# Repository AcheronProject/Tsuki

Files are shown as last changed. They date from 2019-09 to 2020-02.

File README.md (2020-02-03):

# Acheron 60-SM-S-STM32-MX-TH-WI (Codename "Tsuki")

Acheron Logo

See [this page](https://gondolindrim.github.io/AcheronDocs/tsuki/intro.html) for the Tsuki documentation.

## Introduction

Tsuki is a universal 60% PCB, supporting per-key lighting using single-color LEDs, RGB underglow using WS2812C RGB LEDs and a multitude of layouts:

- Default ANSI bottom row;
- Classic HHKB (6.0u spacebar) bottom row;
- Tsangan bottom row (7.0u spacebar, also known as "simmetrical HHKB")
- Split backspace;
- Split left and right shifts;
- ISO and UK-ISO;
- ABNT and ABNT2 layouts.

Tsuki was heavily based on the [GH60](https://github.com/komar007/gh60), a legendary PCB designed by Komar with extensive feedback from the community.

## Contributors

- Raphael "ArcticFox" Hochheim for helping choosing the compatible layouts and the naming of the PCBs
- Felipe 'MrKeebs" Coury who paid for the V1 prototypes and helped immensely by funding my learning

## Renders

Click at the images to zoom in.

Renders generated by the [tracespace.io](https://tracespace.io/view/) site.

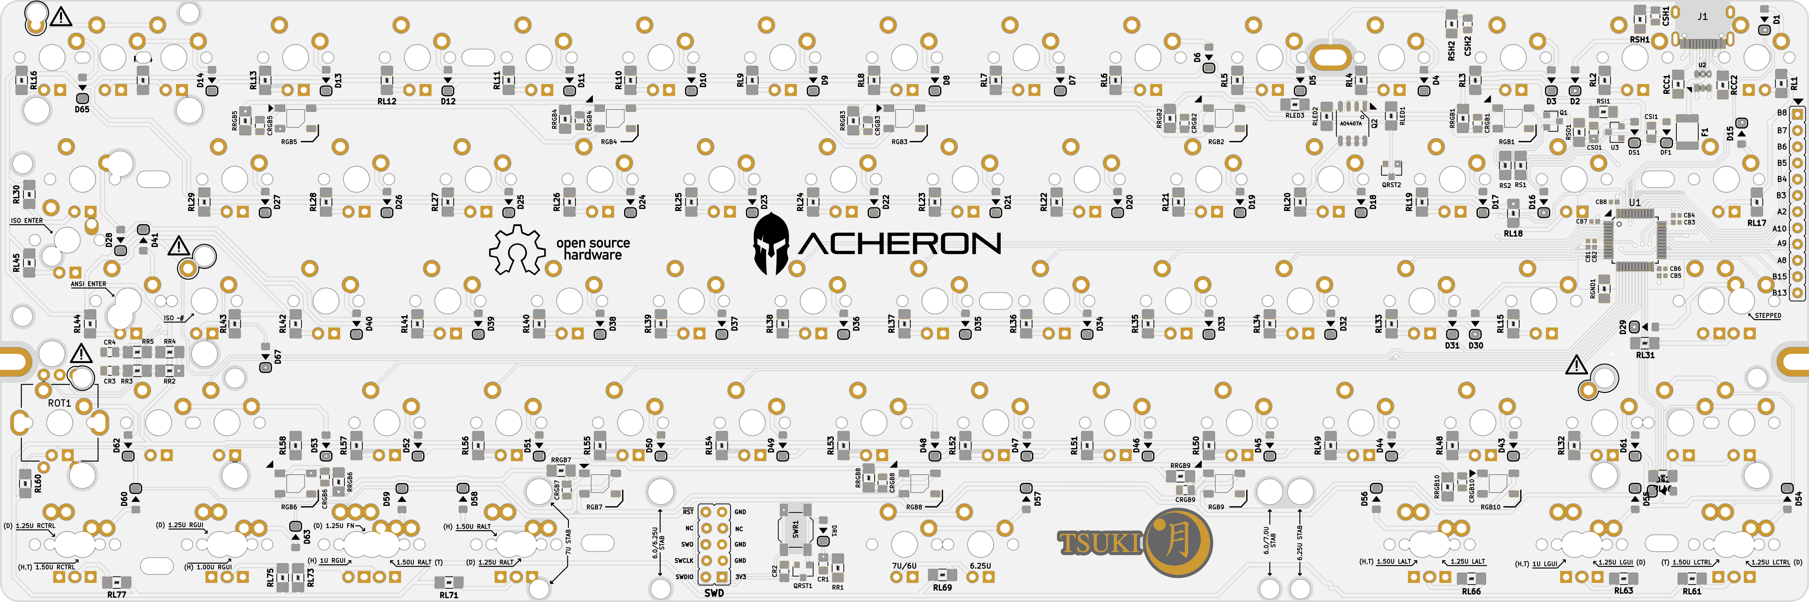
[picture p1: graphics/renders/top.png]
TsukiPCB Top Render


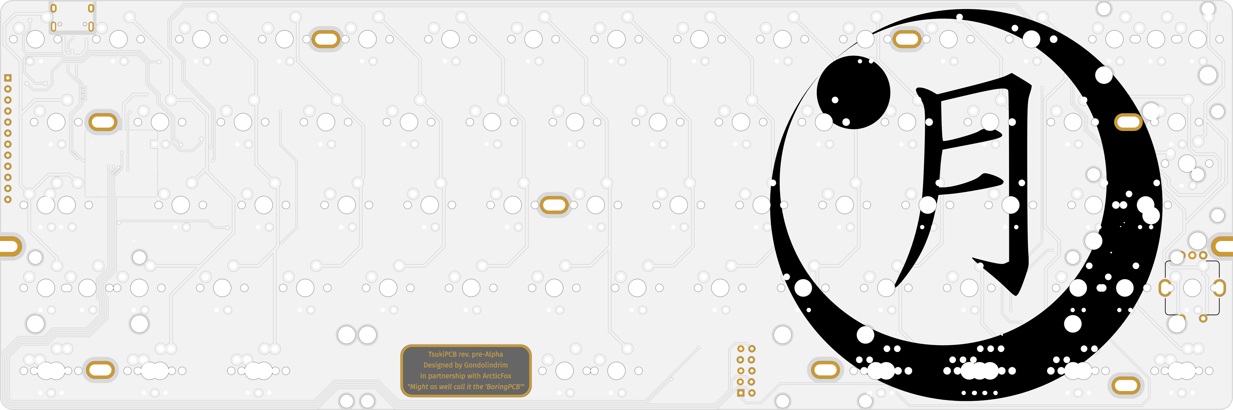
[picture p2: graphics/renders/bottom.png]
TsukiPCB Bottom Render


## Supported layouts

Click [this link](http://www.keyboard-layout-editor.com/#/gists/a08f081ffa5e553c9e5ae899616ba2f6) for the KLE file for the Tsuki.

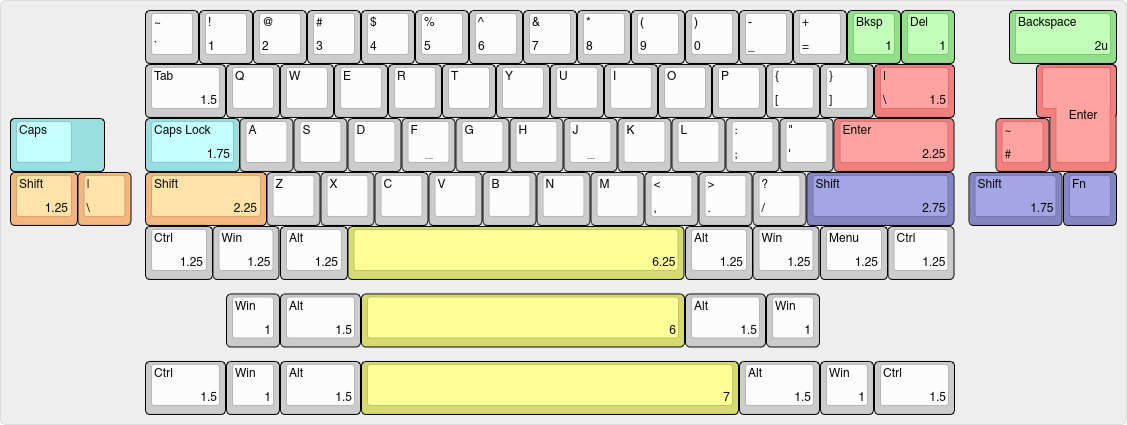
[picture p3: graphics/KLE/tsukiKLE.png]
Tsuki layouts


## Copyright notice

This project is released under the Acheron Open-Hardware License V1.2. For the license, please refer to the LICENCE.md file.

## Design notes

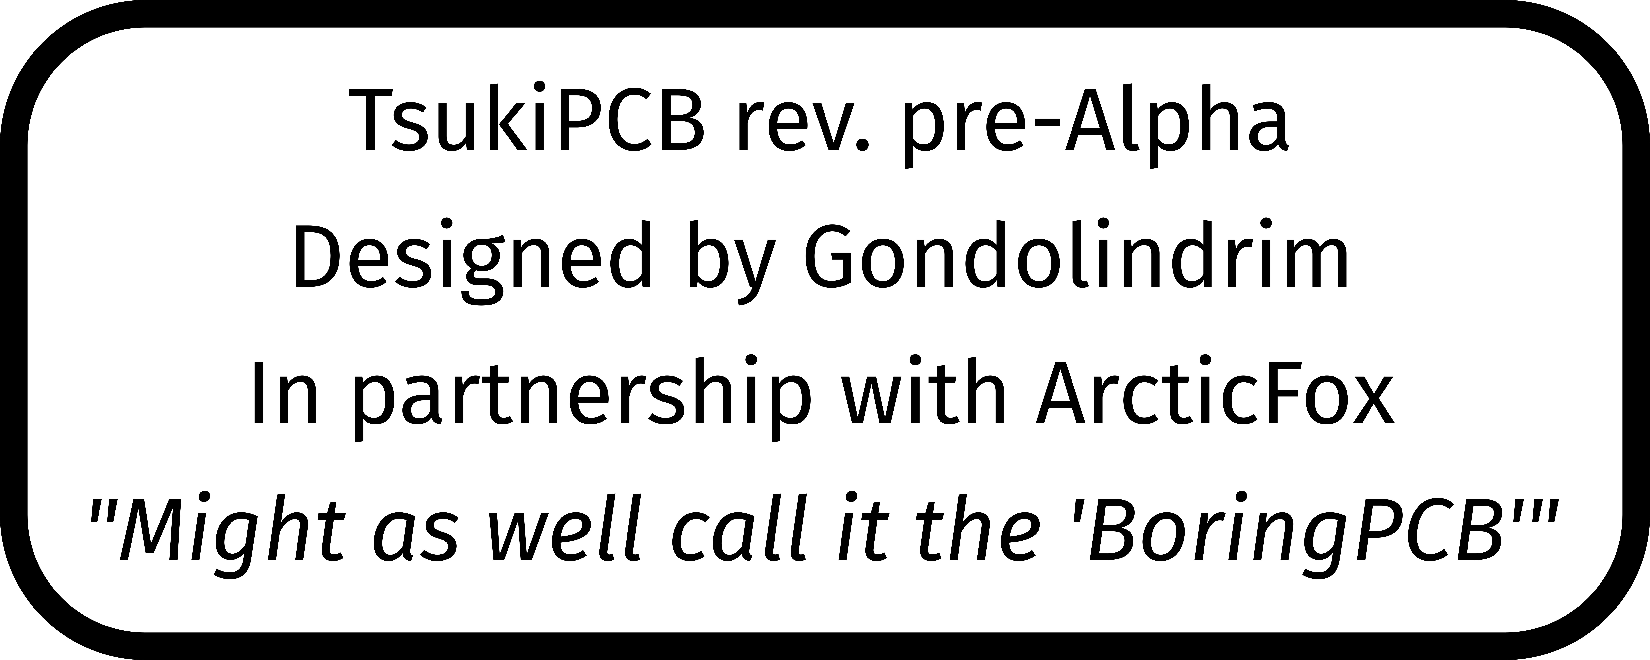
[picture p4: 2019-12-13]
graphics/tsukiLabel/tsukiLabel.png

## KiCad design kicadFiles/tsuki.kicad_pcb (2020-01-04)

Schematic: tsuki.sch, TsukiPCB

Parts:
CB1, CB3, CB7: 100n; C_0402_1005Metric
CB2: 100nF; C_0402_1005Metric
CB4, CB8: 4.7uF; C_0402_1005Metric
CB5: 1uF; C_0402_1005Metric
CB6: 10n; C_0402_1005Metric
CR1, CR2: 100n; C_0805_2012Metric
CR3: 4.7n; C_0805_2012Metric_Pad1.15x1.40mm_HandSolder
CR4: 10u; C_0805_2012Metric_Pad1.15x1.40mm_HandSolder
CRGB1, CRGB2, CRGB3, CRGB4, CRGB5, CRGB6, CRGB7, CRGB8, CRGB9, CRGB10: 100n; C_0805_2012Metric
CSH1, CSH2: 4.7nF; C_0805_2012Metric
CSI1: 1u; C_0805_2012Metric_Pad1.15x1.40mm_HandSolder
CSO1: 1u; C_0805_2012Metric_Pad1.15x1.40mm_HandSolder
D1, D2, D3, D4, D5, D6, D7, D8, D9, D10, D11, D12, D13, D14, D15, D16, D17, D18, D19, D20, D21, D22, D23, D24, D25, D26, D27, D28, D29, D30, D31, D32, D33, D34, D35, D36, D37, D38, D39, D40, D41, D42, D43, D44, D45, D46, D47, D48, D49, D50, D51, D52, D53, D54, D55, D56, D57, D58, D59, D60, D61, D62, D63, D64, D65: 1N4148; D_SOD-123
DF1: SMF9.0CA; D_SOD-123
DR1: 1N4148; D_SOD-123
DS1: RB060M-60TR; D_SOD-123
F1: 1.5A trip PTC; Fuse_1812_4532
H1, H6: Half Side Hole; halfSideHole
H2: Mounting Hole; MoutingHole_Oval_BackOnly_7mm_5.0x2.5mm
H3, H4, H5, H7, H9, H10: Oval Mounting Hole; MoutingHole_Oval_BackOnly_7mm_5.0x2.5mm
H8: Oval Mounting Hole; MoutingHole_Oval_7mm_5.0x2.5mm
J1: Conn_ARM_JTAG_SWD_10
J2: Conn_01x12; PinHeader_1x10_P2.54mm_Vertical
J3: TYPE-C-31-M12_13; TYPE-C-31-M-12
L1: OSHLogo; osh-logo
L2, L3, L5, L7: Warning; warning_sign_3.6x3.2mm
L4: Tsuki Logo; tsukiLogo_plated_25x11mm
L6: Acheron Logo; acheronLong
L8: TsukiLabel; tsukiLabel_30x12mm
L9: Tsuki Big Logo; tsukiLogo_90x115mm
LED1, LED2, LED3, LED4, LED5, LED6, LED7, LED8, LED9, LED10, LED11, LED12, LED13, LED14, LED15, LED16, LED17, LED18, LED19, LED20, LED21, LED22, LED23, LED24, LED25, LED26, LED27, LED28, LED29, LED30, LED31, LED32, LED33, LED34, LED35, LED36, LED37, LED38, LED39, LED40, LED41, LED42, LED43, LED44, LED45, LED46, LED47, LED48, LED49, LED50, LED51, LED52, LED53, LED54, LED55, LED56, LED57, LED58, LED59, LED60, LED61, LED62, LED63, LED64, LED65, LED66, LED67, LED68, LED69, LED70, LED71, LED72, LED73, LED74, LED75, LED76, LED77, LED78, LED79: LED; LED_THT_2.54mm
Q1: BSS138; SOT-23
QLED1: AO4407A; SOIC-8
QLED2: DTC123J; SOT-23
QRST1: DTC123J; SOT-23
RCC1, RCC2: 5.1k; R_SMD_1206
RGB1, RGB2, RGB3, RGB4, RGB5, RGB6, RGB7, RGB8, RGB9, RGB10: WS2812B; LED_WS2812B_5.0x5.0mm_P3.2mm
RGND1: R01; R_SMD_1206
RL1, RL2, RL3, RL4, RL5, RL6, RL7, RL8, RL9, RL10, RL11, RL12, RL13, RL14, RL15, RL16, RL17, RL18, RL19, RL20, RL21, RL22, RL23, RL24, RL25, RL26, RL27, RL28, RL29, RL30, RL31, RL32, RL33, RL34, RL35, RL36, RL37, RL38, RL39, RL40, RL41, RL42, RL43, RL44, RL45, RL46, RL47, RL48, RL49, RL50, RL51, RL52, RL53, RL54, RL55, RL56, RL57, RL58, RL59, RL60, RL61, RL62, RL63, RL64, RL65, RL66: 420R; R_SMD_1206
RLED1, RLED2: 10k; R_SMD_1206
RLED3: 100R; R_SMD_1206
ROT1: Rotary_Encoder_Switch; ALPS_EC11E
RR1, RR2, RR3, RR4: 10k; R_SMD_1206
RR5: 100k; R_SMD_1206
RRGB1, RRGB2, RRGB3, RRGB4, RRGB5, RRGB6, RRGB7, RRGB8, RRGB9, RRGB10: 5.1R; R_SMD_1206
RS1, RS2: 10k; R_SMD_1206
RSH1, RSH2: 1M; R_SMD_1206
RSI1: 100k; R_SMD_1206
RSO1: 100k; R_SMD_1206
SW1: 1U LBKSP; MX100
SW2: ESC; MX100
SW3: 1; MX100
SW4: 2; MX100
SW5: 3; MX100
SW6: 4; MX100
SW7: 5; MX100
SW8: 6; MX100
SW9: 7; MX100
SW10: 8; MX100
SW11: 9; MX100
SW12: 0; MX100
SW13: -_; MX100
SW14: +=; MX100
SW15: 2U BKSP; MX200
SW16: TAB_150; MX150
SW17: Q; MX100
SW18: W; MX100
SW19: E; MX100
SW20: R; MX100
SW21: T; MX100
SW22: Y; MX100
SW23: U; MX100
SW24: I; MX100
SW25: O; MX100
SW26: P; MX100
SW27: [{; MX100
SW28: ]}; MX100
SW29: 1U RBKSP; MX100
SW30: STEPPED_CAPS_125; MX125
SW31: CAPS_175; MX175
SW32: A; MX100
SW33: S; MX100
SW34: D; MX100
SW35: F; MX100
SW36: G; MX100
SW37: H; MX100
SW38: J; MX100
SW39: K; MX100
SW40: L; MX100
SW41: :;; MX100
SW42: \"'; MX100
SW43: \\|_150; MX150
SW44: ENTER_225; MX225
SW45: ISO_ENTER; MX_ISOEnter_Vertical_LED
SW46: RSHIFT_175; MX175
SW47: LSHIFT_225; MX225
SW48: ISO_100; MX100
SW49: Z; MX100
SW50: X; MX100
SW51: C; MX100
SW52: V; MX100
SW53: B; MX100
SW54: N; MX100
SW55: M; MX100
SW56: <,; MX100
SW57: >.; MX100
SW58: ?/; MX100
SW59: RSHIFT_275; MX275
SW60: ISO_\\_100; MX100
SW61: LSHIFT_125; MX125
SW62: LCTRL_150; MX150
SW63, SW77: RALT_150; MX150
SW64, SW78: RGUI_100; MX100
SW65: FN_100; MX100
SW66: LCTRL_125; MX125
SW67: LGUI_125; MX125
SW68: LALT_125; MX125
SW69: SPACE_625; MX625R
SW70: RALT_125; MX125
SW71: FN_125; MX125
SW72: RGUI_125; MX125
SW73: RCTRL_125; MX125
SW74: LGUI_100; MX100
SW75: LALT_150; MX150
SW76: SPACE_700; MX700R
SW79: RCTRL_150; MX150
SWR1: SW_Push; smdPushBtn
U1: USBLC6-2SC6; SOT-23-6
U2: STM32F072-LQFP48; LQFP-48_7x7mm_P0.5mm
U3: MCP1700-3302E_SOT23; SOT-23

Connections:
3.3V: CB1.2, CB2.1, CB3.2, CB4.2, CB5.2, CB6.2, CB7.2, CB8.2, CSO1.2, DS1.2 (A), J1.1 (VTref), Q1.1 (G), RR1.1, RR2.1, RS2.1, RSO1.1, SWR1.1, U2.1 (VBAT), U2.9 (VDDA), U2.24 (VDD), U2.36 (VDDIO2), U2.48 (VDD), U3.2 (VO)
5V: CSI1.2, DF1.1 (A1), DS1.1 (K), F1.1, QLED1.1 (S), QLED1.2 (S), QLED1.3 (S), RLED1.1, RLED2.2, RRGB1.1, RRGB2.1, RRGB3.1, RRGB4.1, RRGB5.1, RRGB6.1, RRGB7.1, RRGB8.1, RRGB9.1, RRGB10.1, RS1.1, RSI1.1, U3.3 (VI)
/SHIELD: CSH2.2, J3.S (SHIELD), RSH2.1
BOOT0: CR4.2, DR1.1 (K), RR5.1, U2.44 (BOOT0)
CASE: CSH1.2, H8.1, RSH1.1
Col1: SW2.1 (Col), SW16.1 (Col), SW30.2 (Row), SW31.1 (Col), SW47.1 (Col), SW61.1 (Col), SW62.1 (Col), SW66.1 (Col), U2.25 (PB12)
Col2: SW3.1 (Col), SW17.1 (Col), SW32.1 (Col), SW48.1 (Col), SW67.1 (Col), SW74.1 (Col), U2.12 (PA2/ADC_IN2)
Col3: SW4.1 (Col), SW18.1 (Col), SW33.1 (Col), SW49.1 (Col), SW68.1 (Col), SW75.1 (Col), U2.11 (PA1/ADC_IN1)
Col4: SW5.1 (Col), SW19.1 (Col), SW34.1 (Col), SW50.1 (Col), U2.10 (PA0/ADC_IN0)
Col5: SW6.1 (Col), SW20.1 (Col), SW35.1 (Col), SW51.1 (Col), U2.6 (PF1/OSC_OUT)
Col6: SW7.1 (Col), SW21.1 (Col), SW36.1 (Col), SW52.1 (Col), U2.5 (PF0/OSC_IN)
Col7: SW8.1 (Col), SW22.1 (Col), SW37.1 (Col), SW53.1 (Col), SW69.1 (Col), SW76.1 (Col), U2.4 (PC15/OSC32_OUT)
Col8: SW9.1 (Col), SW23.1 (Col), SW38.1 (Col), SW54.1 (Col), U2.3 (PC14/OSC32_IN)
Col9: SW10.1 (Col), SW24.1 (Col), SW39.1 (Col), SW55.1 (Col), U2.20 (PB2)
Col10: SW11.1 (Col), SW25.1 (Col), SW40.1 (Col), SW56.1 (Col), SW63.1 (Col), SW70.1 (Col), U2.19 (PB1/TIM3_CH4/TIM14_CH1/ADC_IN9)
Col11: SW12.1 (Col), SW26.1 (Col), SW41.1 (Col), SW57.1 (Col), SW64.1 (Col), SW71.1 (Col), SW77.1 (Col), U2.18 (PB0/TIM3_CH3/ADC_IN8)
Col12: SW13.1 (Col), SW27.1 (Col), SW42.1 (Col), SW58.1 (Col), SW72.1 (Col), SW78.1 (Col), U2.17 (PA7/TIM3_CH2/TIM14_CH1/ADC_IN7)
Col13: SW14.1 (Col), SW28.1 (Col), SW43.1 (Col), SW46.1 (Col), SW59.1 (Col), SW73.1 (Col), SW79.1 (Col), U2.15 (PA5/ADC_IN5/DAC_OUT2)
Col14: ROT1.S2, SW1.1 (Col), SW15.1 (Col), SW29.1 (Col), SW44.1 (Col), SW45.1 (Col), SW60.1 (Col), SW65.1 (Col), U2.14 (PA4/TIM14_CH1/ADC_IN4)
D+: U1.3 (IO2), U2.33 (USB_DP/PA12)
D-: U1.1 (IO1), U2.32 (USB_DM/TIM1_CH4/PA11)
DBus+: J3.A7 (D-), J3.B7 (D-), U1.4 (IO2)
DBus-: J3.A6 (D+), J3.B6 (D+), U1.6 (IO1)
ENC_A: CR2.1, RR4.2, U2.46 (SPI2_NSS/I2S2_WS/I2C1_SDA/TIM17_CH1/PB9)
ENC_B: CR1.1, RR3.2, U2.2 (PC13)
Extra3: J2.1, U2.42 (I2C1_SCL/PB6)
Extra4: J2.2, U2.41 (SPI1_MOSI/I2S1_SD/TIM3_CH2/PB5)
Extra5: J2.3, U2.40 (SPI1_MISO/I2S1_MCK/TIM3_CH1/PB4)
Extra6: J2.4, U2.39 (SPI1_SCK/I2S1_CK/TIM2_CH2/PB3)
Extra7: J2.5, U2.38 (PA2)
Extra8: J2.6, U2.31 (TIM1_CH3/PA10)
Extra9: J2.7, U2.30 (TIM1_CH2/PA9)
Extra10: J2.8, U2.29 (TIM1_CH1/PA8)
Extra11: J2.9, U2.27 (PB14/SPI2_MISO/I2S2_MCK/I2C2_SDA/TIM15_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)
Extra12: J2.10, U2.26 (SPI2_SCK/I2S2_CK/I2C2_SCL/PB13)
GND: CR1.2, CR2.2, CR3.2, CR4.1, CRGB1.2, CRGB2.2, CRGB3.2, CRGB4.2, CRGB5.2, CRGB6.2, CRGB7.2, CRGB8.2, CRGB9.2, CRGB10.2, CSH1.1, CSH2.1, CSI1.1, CSO1.1, DF1.2 (A2), J1.3 (GND), J1.5 (GND), J1.9 (GNDDetect), J3.A1 (GND), J3.B1 (GND), LED1.K, LED2.K, LED3.K, LED4.K, LED5.K, LED6.K, LED7.K, LED8.K, LED9.K, LED10.K, LED11.K, LED12.K, LED13.K, LED14.K, LED15.K, LED16.K, LED17.K, LED18.K, LED19.K, LED20.K, LED21.K, LED22.K, LED23.K, LED24.K, LED25.K, LED26.K, LED27.K, LED28.K, LED29.K, LED30.K, LED31.K, LED32.K, LED33.K, LED34.K, LED35.K, LED36.K, LED37.K, LED38.K, LED39.K, LED40.K, LED41.K, LED42.K, LED43.K, LED44.K, LED45.K, LED46.K, LED47.K, LED48.K, LED49.K, LED50.K, LED51.K, LED52.K, LED53.K, LED54.K, LED55.K, LED56.K, LED57.K, LED58.K, LED59.K, LED60.K, LED61.K, LED62.K, LED63.K, LED64.K, LED65.K, LED66.K, LED67.K, LED68.K, LED69.K, LED70.K, LED71.K, LED72.K, LED73.K, LED74.K, LED75.K, LED76.K, LED77.K, LED78.K, LED79.K, QLED2.2 (E), QRST1.2 (E), RCC1.1, RCC2.1, RGB1.3 (VSS), RGB2.3 (VSS), RGB3.3 (VSS), RGB4.3 (VSS), RGB5.3 (VSS), RGB6.3 (VSS), RGB7.3 (VSS), RGB8.3 (VSS), RGB9.3 (VSS), RGB10.3 (VSS), RGND1.2, ROT1.C, RR5.2, RSH1.2, RSH2.2, RSI1.2, RSO1.2, U1.2 (GND), U3.1 (GND)
GNDD: CB1.1, CB2.2, CB3.1, CB4.1, CB5.1, CB6.1, CB7.1, CB8.1, RGND1.1, U2.8 (VSSA), U2.23 (VSS), U2.35 (VSS), U2.47 (VSS)
L1: D57.2 (A), SW62.2 (Row), SW66.2 (Row)
L2: D63.2 (A), SW67.2 (Row), SW74.2 (Row)
L3: D64.2 (A), SW68.2 (Row), SW75.2 (Row)
L5: D58.2 (A), SW69.2 (Row), SW76.2 (Row)
L6: D59.2 (A), SW63.2 (Row), SW70.2 (Row)
L7: D60.2 (A), SW64.2 (Row), SW71.2 (Row), SW77.2 (Row)
L8: D62.2 (A), SW72.2 (Row), SW78.2 (Row)
L9: D65.2 (A), SW73.2 (Row), SW79.2 (Row)
LED_PWM: QLED2.1 (B), U2.16 (PA6/ADC_IN6/TIM3_CH1/TIM16_CH1)
NRST: CR3.1, J1.10 (~RESET~), QRST1.3 (C), U2.7 (NRST)
unnamed: CRGB1.1, RGB1.1 (VDD), RRGB1.2
unnamed: CRGB2.1, RGB2.1 (VDD), RRGB2.2
unnamed: CRGB3.1, RGB3.1 (VDD), RRGB3.2
unnamed: CRGB4.1, RGB4.1 (VDD), RRGB4.2
unnamed: CRGB5.1, RGB5.1 (VDD), RRGB5.2
unnamed: CRGB6.1, RGB6.1 (VDD), RRGB6.2
unnamed: CRGB7.1, RGB7.1 (VDD), RRGB7.2
unnamed: CRGB8.1, RGB8.1 (VDD), RRGB8.2
unnamed: CRGB9.1, RGB9.1 (VDD), RRGB9.2
unnamed: CRGB10.1, RGB10.1 (VDD), RRGB10.2
unnamed: D1.2 (A), SW2.2 (Row)
unnamed: D2.2 (A), SW3.2 (Row)
unnamed: D3.2 (A), SW4.2 (Row)
unnamed: D4.2 (A), SW5.2 (Row)
unnamed: D5.2 (A), SW6.2 (Row)
unnamed: D6.2 (A), SW7.2 (Row)
unnamed: D7.2 (A), SW8.2 (Row)
unnamed: D8.2 (A), SW9.2 (Row)
unnamed: D9.2 (A), SW10.2 (Row)
unnamed: D10.2 (A), SW11.2 (Row)
unnamed: D11.2 (A), SW12.2 (Row)
unnamed: D12.2 (A), SW13.2 (Row)
unnamed: D13.2 (A), SW14.2 (Row)
unnamed: D14.2 (A), SW1.2 (Row), SW15.2 (Row)
unnamed: D15.2 (A), SW16.2 (Row)
unnamed: D16.2 (A), SW17.2 (Row)
unnamed: D17.2 (A), SW18.2 (Row)
unnamed: D18.2 (A), SW19.2 (Row)
unnamed: D19.2 (A), SW20.2 (Row)
unnamed: D20.2 (A), SW21.2 (Row)
unnamed: D21.2 (A), SW22.2 (Row)
unnamed: D22.2 (A), SW23.2 (Row)
unnamed: D23.2 (A), SW24.2 (Row)
unnamed: D24.2 (A), SW25.2 (Row)
unnamed: D25.2 (A), SW26.2 (Row)
unnamed: D26.2 (A), SW27.2 (Row)
unnamed: D27.2 (A), SW28.2 (Row)
unnamed: D28.2 (A), SW29.2 (Row)
unnamed: D29.2 (A), SW30.1 (Col), SW31.2 (Row)
unnamed: D30.2 (A), SW32.2 (Row)
unnamed: D31.2 (A), SW33.2 (Row)
unnamed: D32.2 (A), SW34.2 (Row)
unnamed: D33.2 (A), SW35.2 (Row)
unnamed: D34.2 (A), SW36.2 (Row)
unnamed: D35.2 (A), SW37.2 (Row)
unnamed: D36.2 (A), SW38.2 (Row)
unnamed: D37.2 (A), SW39.2 (Row)
unnamed: D38.2 (A), SW40.2 (Row)
unnamed: D39.2 (A), SW41.2 (Row)
unnamed: D40.2 (A), SW42.2 (Row)
unnamed: D41.2 (A), SW43.2 (Row)
unnamed: D42.2 (A), SW44.2 (Row), SW45.2 (Row)
unnamed: D43.2 (A), SW47.2 (Row), SW61.2 (Row)
unnamed: D44.2 (A), SW48.2 (Row)
unnamed: D45.2 (A), SW49.2 (Row)
unnamed: D46.2 (A), SW50.2 (Row)
unnamed: D47.2 (A), SW51.2 (Row)
unnamed: D48.2 (A), SW52.2 (Row)
unnamed: D49.2 (A), SW53.2 (Row)
unnamed: D50.2 (A), SW54.2 (Row)
unnamed: D51.2 (A), SW55.2 (Row)
unnamed: D52.2 (A), SW56.2 (Row)
unnamed: D53.2 (A), SW57.2 (Row)
unnamed: D54.2 (A), SW58.2 (Row)
unnamed: D55.2 (A), SW46.2 (Row), SW59.2 (Row)
unnamed: D56.2 (A), SW60.2 (Row)
unnamed: DR1.2 (A), QRST1.1 (B), SWR1.2
unnamed: J3.A5 (CC1), RCC1.2
unnamed: J3.B5 (CC2), RCC2.2
unnamed: LED1.A, RL1.1
unnamed: LED2.A, RL2.1
unnamed: LED3.A, RL3.1
unnamed: LED4.A, RL4.1
unnamed: LED5.A, RL5.1
unnamed: LED6.A, RL6.1
unnamed: LED7.A, RL7.1
unnamed: LED8.A, RL8.1
unnamed: LED9.A, RL9.1
unnamed: LED10.A, RL10.1
unnamed: LED11.A, RL11.1
unnamed: LED12.A, RL12.1
unnamed: LED13.A, RL13.1
unnamed: LED14.A, LED15.A, RL14.1
unnamed: LED16.A, RL15.1
unnamed: LED17.A, RL16.1
unnamed: LED18.A, RL17.1
unnamed: LED19.A, RL18.1
unnamed: LED20.A, RL19.1
unnamed: LED21.A, RL20.1
unnamed: LED22.A, RL21.1
unnamed: LED23.A, RL22.1
unnamed: LED24.A, RL23.1
unnamed: LED25.A, RL24.1
unnamed: LED26.A, RL25.1
unnamed: LED27.A, RL26.1
unnamed: LED28.A, RL27.1
unnamed: LED29.A, RL28.1
unnamed: LED30.A, RL29.1
unnamed: LED31.A, LED32.A, RL30.1
unnamed: LED33.A, RL31.1
unnamed: LED34.A, RL32.1
unnamed: LED35.A, RL33.1
unnamed: LED36.A, RL34.1
unnamed: LED37.A, RL35.1
unnamed: LED38.A, RL36.1
unnamed: LED39.A, RL37.1
unnamed: LED40.A, RL38.1
unnamed: LED41.A, RL39.1
unnamed: LED42.A, RL40.1
unnamed: LED43.A, RL41.1
unnamed: LED44.A, RL42.1
unnamed: LED45.A, RL43.1
unnamed: LED46.A, RL44.1
unnamed: LED47.A, LED48.A, RL45.1
unnamed: LED49.A, RL46.1
unnamed: LED50.A, RL47.1
unnamed: LED51.A, RL48.1
unnamed: LED52.A, RL49.1
unnamed: LED53.A, RL50.1
unnamed: LED54.A, RL51.1
unnamed: LED55.A, RL52.1
unnamed: LED56.A, RL53.1
unnamed: LED57.A, RL54.1
unnamed: LED58.A, RL55.1
unnamed: LED59.A, RL56.1
unnamed: LED60.A, RL57.1
unnamed: LED61.A, LED62.A, RL58.1
unnamed: LED63.A, LED64.A, RL59.1
unnamed: LED65.A, LED66.A, RL60.1
unnamed: LED67.A, LED68.A, RL61.1
unnamed: LED69.A, LED70.A, RL62.1
unnamed: LED71.A, LED72.A, RL63.1
unnamed: LED73.A, LED74.A, LED75.A, RL64.1
unnamed: LED76.A, LED77.A, RL65.1
unnamed: LED78.A, LED79.A, RL66.1
unnamed: QLED1.4 (G), RLED2.1, RLED3.1
unnamed: QLED1.5 (D), QLED1.6 (D), QLED1.7 (D), QLED1.8 (D), RL1.2, RL2.2, RL3.2, RL4.2, RL5.2, RL6.2, RL7.2, RL8.2, RL9.2, RL10.2, RL11.2, RL12.2, RL13.2, RL14.2, RL15.2, RL16.2, RL17.2, RL18.2, RL19.2, RL20.2, RL21.2, RL22.2, RL23.2, RL24.2, RL25.2, RL26.2, RL27.2, RL28.2, RL29.2, RL30.2, RL31.2, RL32.2, RL33.2, RL34.2, RL35.2, RL36.2, RL37.2, RL38.2, RL39.2, RL40.2, RL41.2, RL42.2, RL43.2, RL44.2, RL45.2, RL46.2, RL47.2, RL48.2, RL49.2, RL50.2, RL51.2, RL52.2, RL53.2, RL54.2, RL55.2, RL56.2, RL57.2, RL58.2, RL59.2, RL60.2, RL61.2, RL62.2, RL63.2, RL64.2, RL65.2, RL66.2
unnamed: QLED2.3 (C), RLED1.2, RLED3.2
unnamed: RGB1.2 (DOUT), RGB2.4 (DIN)
unnamed: RGB2.2 (DOUT), RGB3.4 (DIN)
unnamed: RGB3.2 (DOUT), RGB4.4 (DIN)
unnamed: RGB4.2 (DOUT), RGB5.4 (DIN)
unnamed: RGB5.2 (DOUT), RGB6.4 (DIN)
unnamed: RGB6.2 (DOUT), RGB7.4 (DIN)
unnamed: RGB7.2 (DOUT), RGB8.4 (DIN)
unnamed: RGB8.2 (DOUT), RGB9.4 (DIN)
unnamed: RGB9.2 (DOUT), RGB10.4 (DIN)
RGB_3V3: Q1.2 (S), RS2.2, U2.28 (SPI2_MOSI/I2S2_SD/PB15)
RGB_5V: Q1.3 (D), RGB1.4 (DIN), RS1.2
ROT_A: ROT1.A, RR2.2, RR4.1
ROT_B: ROT1.B, RR1.2, RR3.1
ROT_S1: D61.2 (A), ROT1.S1, SW65.2 (Row)
Row1: D1.1 (K), D2.1 (K), D3.1 (K), D4.1 (K), D5.1 (K), D6.1 (K), D7.1 (K), D8.1 (K), D9.1 (K), D10.1 (K), D11.1 (K), D12.1 (K), D13.1 (K), D14.1 (K), U2.45 (I2C1_SCL/TIM16_CH1/PB8)
Row2: D15.1 (K), D16.1 (K), D17.1 (K), D18.1 (K), D19.1 (K), D20.1 (K), D21.1 (K), D22.1 (K), D23.1 (K), D24.1 (K), D25.1 (K), D26.1 (K), D27.1 (K), D28.1 (K), U2.43 (2C1_SDA/PB7)
Row3: D29.1 (K), D30.1 (K), D31.1 (K), D32.1 (K), D33.1 (K), D34.1 (K), D35.1 (K), D36.1 (K), D37.1 (K), D38.1 (K), D39.1 (K), D40.1 (K), D41.1 (K), D42.1 (K), U2.13 (PA3/TIM15_CH2/ADC_IN3)
Row4: D43.1 (K), D44.1 (K), D45.1 (K), D46.1 (K), D47.1 (K), D48.1 (K), D49.1 (K), D50.1 (K), D51.1 (K), D52.1 (K), D53.1 (K), D54.1 (K), D55.1 (K), D56.1 (K), U2.21 (PB10/SPI2_SCK/I2C2_SCL/TIM2_CH3)
Row5: D57.1 (K), D58.1 (K), D59.1 (K), D60.1 (K), D61.1 (K), D62.1 (K), D63.1 (K), D64.1 (K), D65.1 (K), U2.22 (PB11/TIM2_CH4/I2C2_SDA)
SWCLK: J1.4 (SWDCLK/TCK), U2.37 (SWCLK/PA14)
SWDIO: J1.2 (SWDIO/TMS), U2.34 (SWDIO/PA13)
VBUS: F1.2, J3.A4 (VBUS), J3.B4 (VBUS), U1.5 (VBUS)

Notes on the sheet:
Hard reset circuit
Power supply and protection circuit
Logos and flags
Serial programming
[1] STM32F072x8 / STM32F072xB datasheet
REFERENCES
https://www.st.com/resource/en/datasheet/stm32f072rb.pdf
[2] AN4080 Application note
https://www.st.com/content/ccc/resource/technical/document/application_note/c9/19/d7/b8/6b/0e/4c/d3/DM00051986.pdf/files/DM00051986.pdf/jcr:content/translations/en.D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
MCU
USB Connector
Shield
USD ESD
CBx are the bypass capacitors. Their value is specified in reference [2].
Case ESD
Mounting holes
Extra pins
Observation: the 6U spacebar footprint is already covered by the 6.25+7U spacebar footprints
7U Bottom (T for Tsangan bottom)
6.25U Bottom (D for default ANSI)
6U Bottom (H for HHKB)
Switch matrix
RGB Underglow
Per-keys LEDs
Encoder
Warning signs

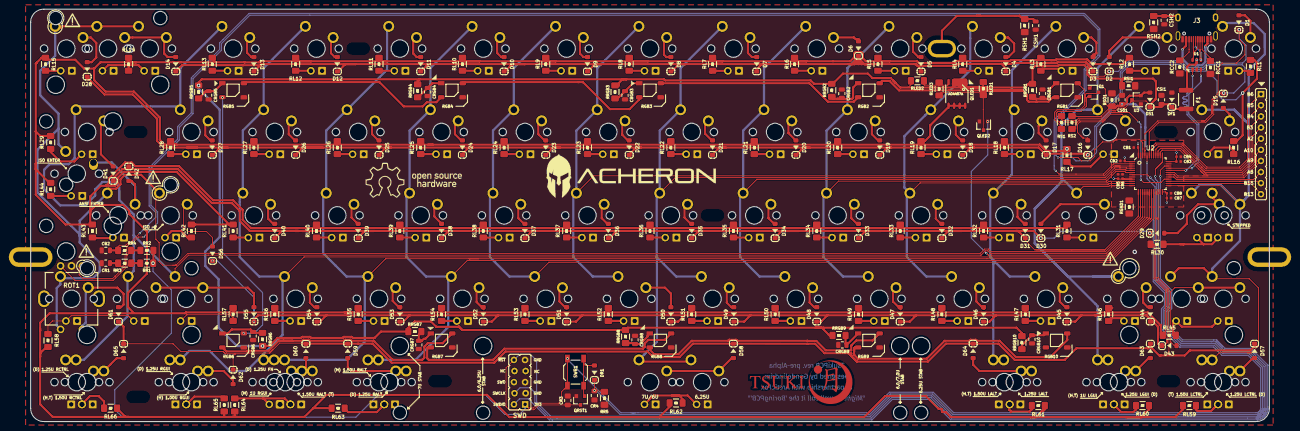
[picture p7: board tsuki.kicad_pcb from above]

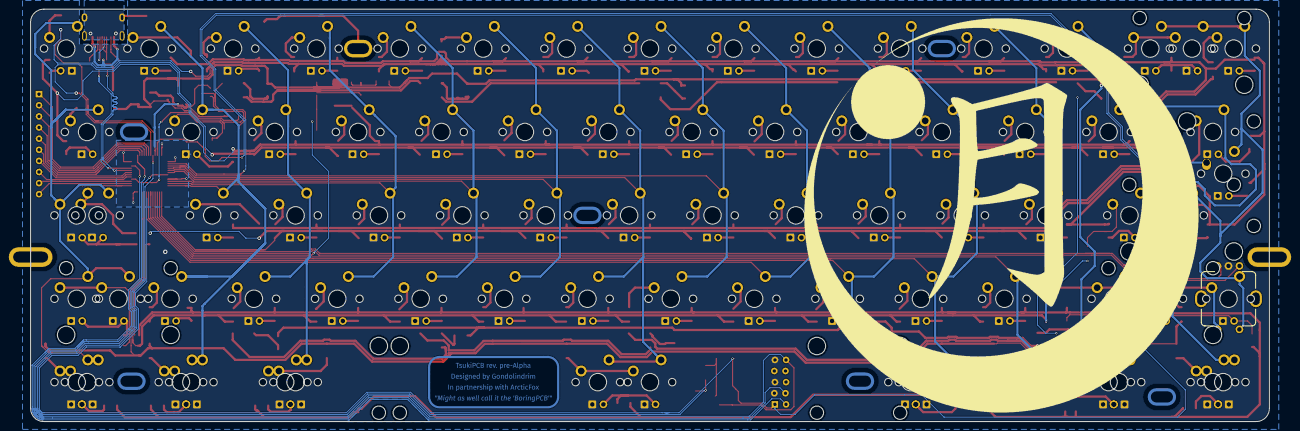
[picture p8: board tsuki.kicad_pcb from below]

Board: 2 copper layers, 283.0 x 94.2 mm, 387 parts (11 on the bottom side), 207 nets.

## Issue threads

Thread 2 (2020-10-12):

3.3V Line Routing Issue

pseudobacon, 2020-10-12:
So I submitted this PCB for printing and noticed that the 3.3V line is crossing a ground hole near RL63

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

Simply shifting this to the left a bit should resolve it

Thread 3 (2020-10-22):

420R 1206 LED resistors difficult to source

pseudobacon, 2020-10-22:
Hi the schematics call for 420 ohm 1206 sized resistors for the LEDs. This specific value and type is very hard to find may I suggest a more common value such as 330R or 470R?

Gondolindrim, 2020-10-22:
Hey @pseudobacon !

Try using 390 ohms. Should be available in most component suppliers!

pseudobacon, 2020-10-23:
Yep much easier to find. Just curious as to why 420 was chosen? It should just affect the brightness of the LED right?

Gondolindrim, 2020-10-23:
The problem with LED resistors is that each LED color has a different forward voltage -- red has around 2.6V, green around 3 and blue around 3.4 . So the same value for these three will yield different current hence distinc lighting levels. If you make the math, 420 is the value that gives acceptable values for all three.

Closed 2020-10-28.

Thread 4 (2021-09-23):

USB DBus+ & DBus- backwards at USB-C port

MasterSpoon, 2021-09-23:
USB A7 (DN1) & B7 (DN2) going to DBus+ which then goes to D+ then to PA12 - USB_DP
USB A6 (DP1) & B6 (DP2) going to DBus- which then goes to D- then to PA11 - USB_DM

These should be reversed with DBus+ going to A6 / B6 and DBus- going to A7 / B
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
7

Gondolindrim, 2021-09-29:
Hi @MasterSpoon ,

The development of Tsuki was cut short due to some unforeseen problems; it indeed needs a complete rework.

For now I do not intend to revisit its design, but in the future it should be redone with some mroe features like multi-STM32 capabilities.

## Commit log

2019-12-12 Removed split space options
    [tsuki.kicad_pcb, tsuki.sch]
2019-12-13 Remove layouts, update li, add label, maintenance
    - The split backspace layouts were removed. This decision was made because I reckoned a very small amount of people would use them, and the PCB is already very compromised material-wise as it is.
    - The Acheron Library was updated, following the updates in other projects
    - A label was added signalling the pre-Revision Alpha
    - The footprints for the holes were all changed for the no-backside version, to avoid any unintended short-circuits
    - Indicative documentation and arrows were added for the bottom row layouts to facilitate building the PCB
    [tsuki.kicad_pcb, tsuki.sch]
2019-12-13 Added clearances to stab holes
    [tsuki.kicad_pcb]
2019-12-15 Added Schottky diodes and TVS
    [tsuki.kicad_pcb, tsuki.sch]
2019-12-15 Added discharge resistors RSI and RSO
    [tsuki.sch]
2019-12-15 Added RGB to schematic
    [tsuki.kicad_pcb, tsuki.sch]
2019-12-15 Added LED control to schematic
    [tsuki.kicad_pcb, tsuki.sch]
2019-12-15 Added bottom row documentation
    [tsuki.kicad_pcb, tsuki.sch]
2019-12-18 Routed second row LEDs
    [tsuki.kicad_pcb, tsuki.sch]
2019-12-18 Finished routing
    [tsuki.kicad_pcb, tsuki.sch]
2020-01-03 Assign col and row pins
    [tsuki.kicad_pcb, tsuki.sch]
2020-01-04 Run DRC, finish pin assignment
    [tsuki.kicad_pcb, tsuki.sch]
2020-01-04 Add rotary encoder support
    [tsuki.kicad_pcb, tsuki.sch]
2020-01-04 Refreshed renders and KLE
    [tsuki.kicad_pcb, tsuki.sch]
2020-01-04 Adjusted schematic
    [tsuki.sch]
2020-01-04 Further adjust schematic
    [tsuki.kicad_pcb, tsuki.sch]
2020-01-04 Refresh KLE, finish PCB and schematic
    [tsuki.kicad_pcb, tsuki.sch]
2020-01-04 Final preparations for release pre-Alpha
    [tsuki.kicad_pcb, tsuki.sch]
